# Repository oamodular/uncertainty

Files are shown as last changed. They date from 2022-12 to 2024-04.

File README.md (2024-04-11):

# *Uncertainty is now OSHW! both the software and the hardware!*

This readme needs to be updated to reflect this and to talk about the many other languages that people have used to create new firmware for Uncertainty. Right now I just want to say that the 4hp DIY version of Uncertainty is still a work in progress. It's been built, but we're in the process of trying to figure out why it doesn't work. The 2hp SMT version of Uncertainty is the one that we sell [here](https://oamodular.org/products/uncertainty).

What remains below is the previous readme. It contains the pinout for Uncertainty's Seeeduino Xiao RP2040 and some example Python code…

# Hack Uncertainty for fun and profit

Uncertainty's firmware is open-source and easy to swap with a humble USB-C cable. You can write your own firmware in C++, MicroPython, CircuitPython, and probably a bunch of other languages. It's startlingly easy to work and this document will outline the whole deal. Let's go…

## Uncertainty’s Heart

We’re working with the mighty RP2040, a dual-core 133 MHz arm processor that is just a silly amount of power for outputting gates. Heck, you can easily overclock to over 300 MHz. Really hoping people make some messed up things.

## Uncertainty’s I/O

- one CV input that can recognize signals -5v to +5v (resolution is functionally close to 10-bit, so there probably isn’t quite the precision for v/oct)
- eight +5v gate outputs that each have their own LED (if you turn on the gate, you turn on the LED; they can’t be decoupled)
- a three pin I2C connector (this feature is experimental and largely untested)

To access this I/O use the following pins. You can use other pins, but they won’t work. I don’t know why you’d use other pins. Use these pins:

| | Pin # |
| --- | --- |
|CV input|26|
|Gate 1|27|
|Gate 2|28|
|Gate 3|29|
|Gate 4|0|
|Gate 5|3|
|Gate 6|4|
|Gate 7|2|
|Gate 8|1|
|I2C SDA|6|
|I2C SCL|7|

## How to reinstall the default firmware

You hold down the boot button when you plug in the USB-C as described in the *Getting started* section. Then you drag ```uncertainty.uf2``` onto the RPI-RP2 disk. It should then unmount. All set! The same works for any .uf2 firmware.

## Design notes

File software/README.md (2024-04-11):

Right now, the default (and shipping) fw are the two in the c++ directory. The plan is to move to circuitpython because we think it’ll be the easiest for people to work with.

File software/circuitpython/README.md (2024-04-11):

# Running the scripts in this directory

Once you flash your Uncertainty with the most recent version of CircuitPython for RP2040, you should see `CIRCUITPY` show up as a disk on your computer. Copy the `examples` and `lib` from this directory into the `CIRCUITPY` drive. Then take make a copy of whatever script your want to run. Name the copy `code.py` and move it to the root level of `CIRCUITPY`. Now you’re running it!

# Making a .uf2 File

You’ll have to make a .uf2 file if you want others to be able to easily install what you have on your `CIRCUITPY`. To do this, install `picotool`. If you have have `brew`, just do a `brew install picotool`. Now run the command `picotool save --all ExampleNameHere.uf2`. Now you can pass this to your friend like a hacker.

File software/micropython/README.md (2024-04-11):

## Lets’s write a simple utility in MicroPython!

We’re going to turn Uncertainty into a device where you send it a voltage to select which of the 8 gates is active. Only one will be active at a time. 0v will activate the first gate. As you move towards -5v or +5v it switches to higher and highter gates, until it gets to gate 8.

### Getting set up

If we were using C we’d write our code in Arduino, but for MicroPython the easiest thing seems to be Thonny. So grab that and launch it. Now connect your Uncertainty to your computer over USB-C while holding down the boot button with the little B on it.

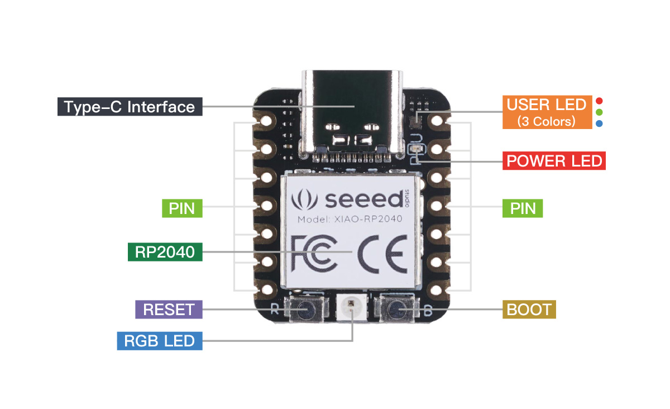
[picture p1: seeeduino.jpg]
Seeeduino Xiao RP2040 with a tiny boot button in the lower-right corner of the board


You should see RPI-RP2 on your desktop and Thonny should prompt you to install MicroPython onto the device. Do it. Just do it. Now Thonny can talk to Uncertainty whenever you plug in USB-C without holding down the boot button.

### Coding the code
These two lines import everything we need to deal get CV in and Gates out:

```python
import time
from machine import Pin, ADC
```

But our code doesn’t know which pin on the RP2040 is the CV in and which are the gates out. So let’s just set up a few variables:

```python
cv_in = ADC(Pin(26))
outs = [Pin(27, Pin.OUT),
        Pin(28, Pin.OUT),
        Pin(29, Pin.OUT),
        Pin(0, Pin.OUT),
        Pin(3, Pin.OUT),
        Pin(4, Pin.OUT),
        Pin(2, Pin.OUT),
        Pin(1, Pin.OUT)]
```

Now let’s make “the loop”. This is all we need to get a chunk of code to run a thousand times a second:

```python
while True:

    # your code here

    time.sleep(0.001)
```

For the actual logic we only need to do three things. (1) Figure out which gate should be active, (2) make it active, and (3) turn off the others.

1. CV comes in as a 16-bit number so we need to scale and offset it to convert the number of the active step:

    ```active_gate = abs(int((cv_in.read_u16() - 32768) / 4096))```

2. To make a gate active we give it a value of 1:

    ```outs[active_gate].value(1)```

3. Now we look through each gate and if it’s not the active one, we turn it off by passing in a value of 0:

```python
    for num in range (8):
        if num != active_gate:
            outs[num].value(0)
```

Now let’s bring this all together and look at the final code:

```python
import time
from machine import Pin, ADC

cv_in = ADC(Pin(26))
outs = [Pin(27, Pin.OUT),
        Pin(28, Pin.OUT),
        Pin(29, Pin.OUT),
        Pin(0, Pin.OUT),
        Pin(3, Pin.OUT),
        Pin(4, Pin.OUT),
        Pin(2, Pin.OUT),
        Pin(1, Pin.OUT)]

while True:

    active_gate = abs(int((cv_in.read_u16() - 32768) / 4096))

    for num in range (8):
        if num != active_gate:
            outs[num].value(0)

    outs[active_gate].value(1)

    time.sleep(0.0001)
```

That’s it. That’s a module, baby. A baby module. Done.

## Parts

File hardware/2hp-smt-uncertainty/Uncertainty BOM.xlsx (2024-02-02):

Item # | Designator | Quantity | Manufacturer | Mfg Part # | Description / Value | Package/Footprint | Type | Notes
1 | R18, R17, R13, R16, R12, R14, R19, R15 | 8 | TE Connectivity / Holsworthy | CRG0603F300R | Thick Film Resistors - SMD CRG0603 1% 300R | 1608 | SMD
2 | R5, R7, R6, R11, R9, R10, R8, R4 | 8 | Panasonic | ERJ-PA3D1001V | Thick Film Resistors - SMD 0603 1Kohm 0.5% Anti-Surge AEC-Q200 | 1608 | SMD
3 | D3, D2, D1 | 3 | Diodes Incorporated | 1N5819HW-7-F | Diode Schottky 40 V 1A Surface Mount SOD-123 | SOD-123 | SMD
4 | PS1 | 1 | Samtec | TSM-105-01-L-DH | TSM - Samtec 2.54mm Dual Row Horizontal Surface Mount Header 5.84mm Post Height (01) | SMD | SMD
5 | H1, H2 | 2 | Wurth Elektronik | 7466303 | Terminals WP-SMRA SMD Block 7mm | SMD | SMD | Component should be mounted so screw hole faces left edge of board
6 | J8, J4, J2, J9, J3, J5, J7, J1, J6 | 9 | Switchcraft | 35RASMT2AHNTRX | Phone Connectors 3.5mm SMT MONO T/R 3A CLOSED | SMD | SMD
7 | D8, D10, D5, D9, D11, D6, D7, D4 | 8 | Kingbright | APPA3010SURCK | Standard LEDs - SMD 3x1mm SMD RA RED | SMD | SMD
8 | U1 | 1 | Texas Instruments | LM1117IMPX-3.3_NOPB | 800-mA 15-V linear voltage regulator | SOT-223-4 | SMD
9 | R1, R3, R2 | 3 | Panasonic | ERJ-2RKF1003X | Thick Film Resistors - SMD 0402 100Kohms 1% AEC-Q200 | 1005 | SMD
10 | C1 | 1 | Panasonic | EEE-FT1E220AR | Aluminum Electrolytic Capacitors - SMD 22uF 25volts 4x5.8mm SMD | SMD | SMD
11 | U5 | 1 | Seeed | 102010428 | RP2040 XIAO RP2040 series ARM Cortex-M0+ MCU 32-Bit Embedded Evaluation Board | SMD | SMD | Please use surface mount soldering, NOT through-hole
12 | U2 | 1 | STMicroelectronics | L7805CDT-TR | Linear Voltage Regulator IC Positive Fixed 1 Output 1.5A DPAK | TO-252 | SMD
13 | U4, U3 | 2 | Texas Instruments | SN74HCS125QDRQ1 | Automotive Schmitt-trigger inputs quadruple bus buffer gates with 3-state outputs 14-SOIC -40 to 125 | SOIC-14 | SMD
14 | J10 | 1 | Samtec | TSM-103-01-L-SH | TSM - Samtec 2.54mm Single Row Horizontal Surface Mount Header 5.84mm Post Height | SMD | SMD

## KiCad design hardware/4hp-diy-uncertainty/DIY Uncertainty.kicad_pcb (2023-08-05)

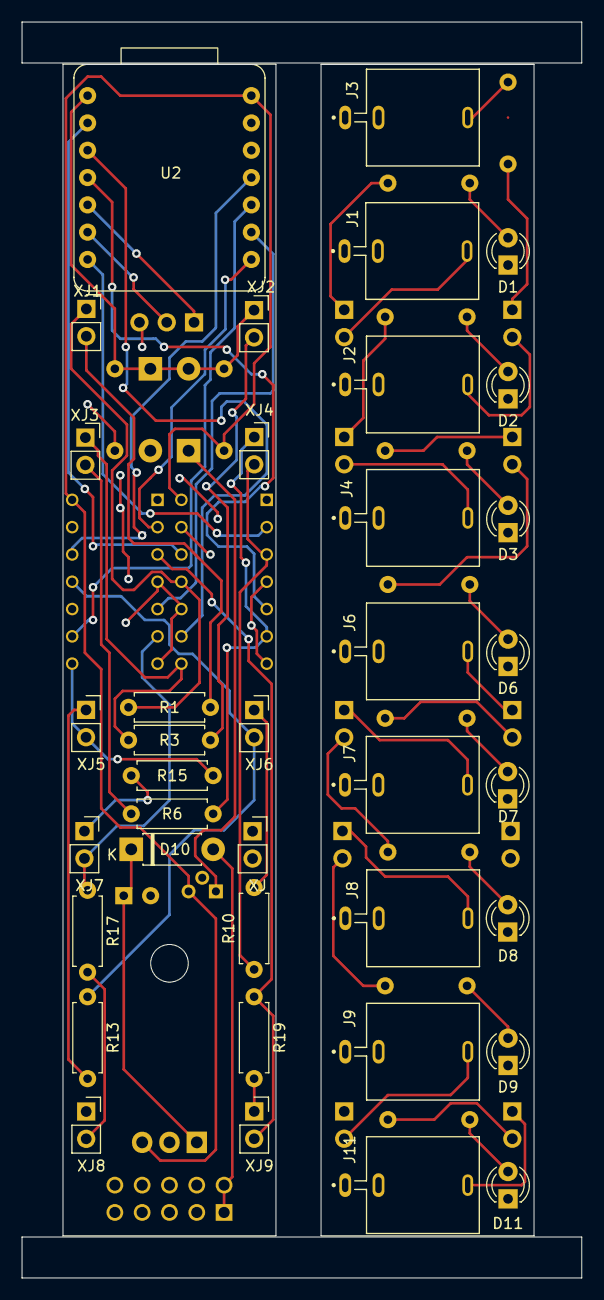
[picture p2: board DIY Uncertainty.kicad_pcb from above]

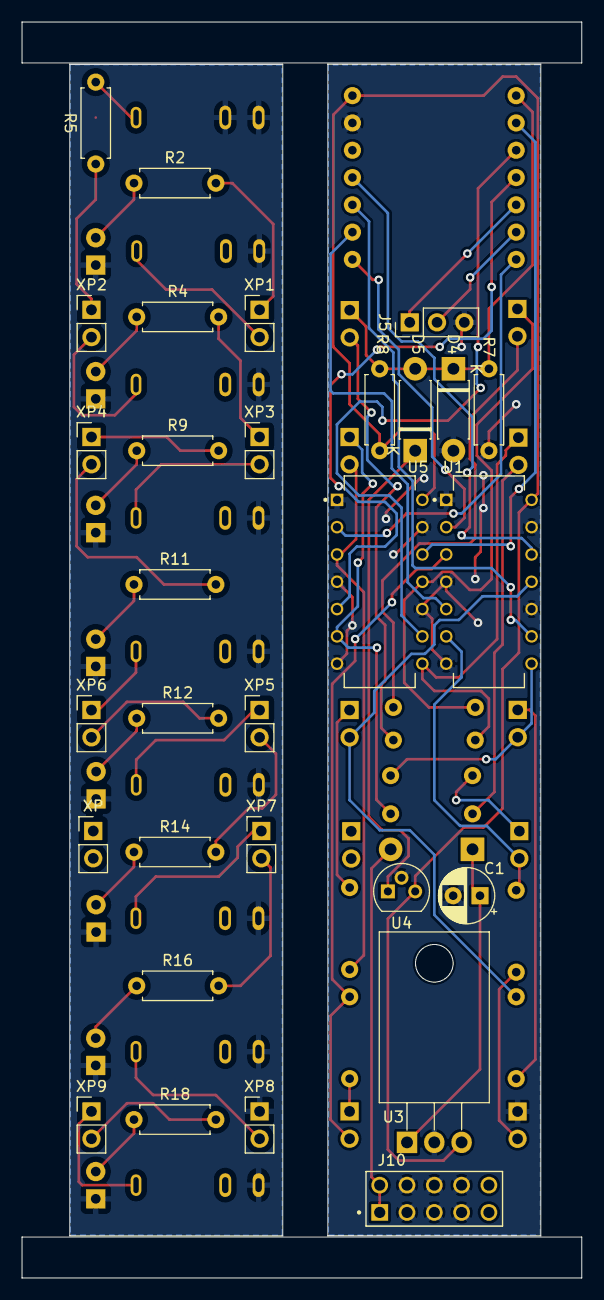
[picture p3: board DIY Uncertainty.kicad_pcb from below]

Board: 2 copper layers, 52.1 x 116.8 mm, 67 parts (30 on the bottom side), 41 nets.

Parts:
C1: 22uF; CP_Radial_D5.0mm_P2.50mm
D1, D2, D3, D6, D7, D8, D9, D11: LED; LED-THT Red Angle130-L-47XEC
D4, D5, D10: 1N5819; D_DO-41_SOD81_P7.62mm_Horizontal
J1, J2, J3, J4, J6, J7, J8, J9, J11: AudioJack2; Socket-3.5mm THT-Thonkiconn PJ398SM-12
J5: Conn_01x03_Pin; PinHeader_1x03_P2.54mm_Vertical
J10: Connector-2x5 2.54p THT-861400102YO9323LF
R1, R3, R6, R10, R13, R15, R17, R19: 1K; R_Axial_DIN0207_L6.3mm_D2.5mm_P7.62mm_Horizontal
R2, R4, R9, R11, R12, R14, R16, R18: 300; R_Axial_DIN0207_L6.3mm_D2.5mm_P7.62mm_Horizontal
R5, R7, R8: 100K; R_Axial_DIN0207_L6.3mm_D2.5mm_P7.62mm_Horizontal
U1, U5: SN74HCT125DE4; Quad Bus-Tri-State Quad Bus non-inverting THT-SN74HCT125NE4
U2: SeeeduinoXIAO; Microcontroller-XIAO RP2040
U3: L7805CV; TO-220-3_Horizontal_TabDown
U4: L78L33ACZTR; TO-92
XJ, XJ1, XJ2, XJ3, XJ4, XJ5, XJ6, XJ7, XJ8, XJ9: PinSocket_1x02_P2.54mm_Vertical
XP, XP1, XP2, XP3, XP4, XP5, XP6, XP7, XP8, XP9: PinHeader_1x02_P2.54mm_Vertical

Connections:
+3.3V: D5.1 (K), U4.1 (VO)
+5V: R8.2, U1.14 (VCC), U2.14 (5V), U3.3 (VO), U4.3 (VI), U5.14 (VCC)
+12V: D10.2 (A), J10.01 (Pin_1), J10.02 (Pin_2)
GND: C1.2, D1.1 (K), D2.1 (K), D3.1 (K), D4.2 (A), D6.1 (K), D7.1 (K), D8.1 (K), D9.1 (K), D11.1 (K), J1.1, J2.1, J3.1, J3.2, J4.1, J5.3, J6.1, J7.1, J8.1, J9.1, J10.03 (Pin_3), J10.04 (Pin_4), J10.05 (Pin_5), J10.06 (Pin_6), J10.07 (Pin_7), J10.08 (Pin_8), J11.1, R7.1, U1.1 (1~OE), U1.4 (2~OE), U1.7 (GND), U1.10 (3~OE), U1.13 (4~OE), U2.13 (GND), U3.2 (GND), U4.2 (GND), U5.1 (1~OE), U5.4 (2~OE), U5.7 (GND), U5.10 (3~OE), U5.13 (4~OE), XJ8.1, XP8.1
unnamed: D1.2 (A), R2.1
unnamed: D2.2 (A), R4.1
unnamed: D3.2 (A), R9.1
unnamed: D4.1 (K), D5.2 (A), R5.1, R7.2, R8.1, U2.1 (PA02_A0_D0), XJ2.1, XP2.1
unnamed: D6.2 (A), R11.1
unnamed: D7.2 (A), R12.1
unnamed: D8.2 (A), R14.1
unnamed: D9.2 (A), R16.1
unnamed: C1.1, D10.1 (K), U3.1 (VI)
unnamed: D11.2 (A), R18.1
unnamed: J1.3, R1.2, XJ1.2, XP1.2
unnamed: J2.3, R3.2, XJ2.2, XP2.2
unnamed: J3.3, R5.2
unnamed: J4.3, R6.2, XJ3.2, XP3.2
unnamed: J5.1, U2.5 (PA8_A4_D4_SDA)
unnamed: J5.2, U2.6 (PA9_A5_D5_SCL)
unnamed: J6.3, R10.2, XJ6.1, XP6.1
unnamed: J7.3, R13.2, XJ5.1, XP5.1
unnamed: J8.3, R15.2, XJ7.1, XP7.1
unnamed: J9.3, R17.2, XJ8.2, XP8.2
unnamed: J11.3, R19.2, XJ9.1, XP9.1
unnamed: U1.2 (1A), U2.8 (PB09_A7_D7_RX)
unnamed: R18.2, R19.1, U1.3 (1Y), XJ9.2, XP9.2
unnamed: U1.5 (2A), U2.9 (PA7_A8_D8_SCK)
unnamed: R16.2, R17.1, U1.6 (2Y), XJ7.2, XP7.2
unnamed: U1.9 (3A), U2.10 (PA5_A9_D9_MISO)
unnamed: R14.2, R15.1, U1.8 (3Y), XJ5.2, XP5.2
unnamed: U1.12 (4A), U2.11 (PA6_A10_D10_MOSI)
unnamed: R12.2, R13.1, U1.11 (4Y), XJ6.2, XP6.2
unnamed: U2.2 (PA4_A1_D1), U5.12 (4A)
unnamed: U2.3 (PA10_A2_D2), U5.9 (3A)
unnamed: U2.4 (PA11_A3_D3), U5.5 (2A)
unnamed: U2.7 (PB08_A6_D6_TX), U5.2 (1A)
unnamed: R10.1, R11.2, U5.3 (1Y), XJ4.2, XP4.2
unnamed: R6.1, R9.2, U5.6 (2Y), XJ4.1, XP4.1
unnamed: R3.1, R4.2, U5.8 (3Y), XJ3.1, XP3.1
unnamed: R1.1, R2.2, U5.11 (4Y), XJ1.1, XP1.1

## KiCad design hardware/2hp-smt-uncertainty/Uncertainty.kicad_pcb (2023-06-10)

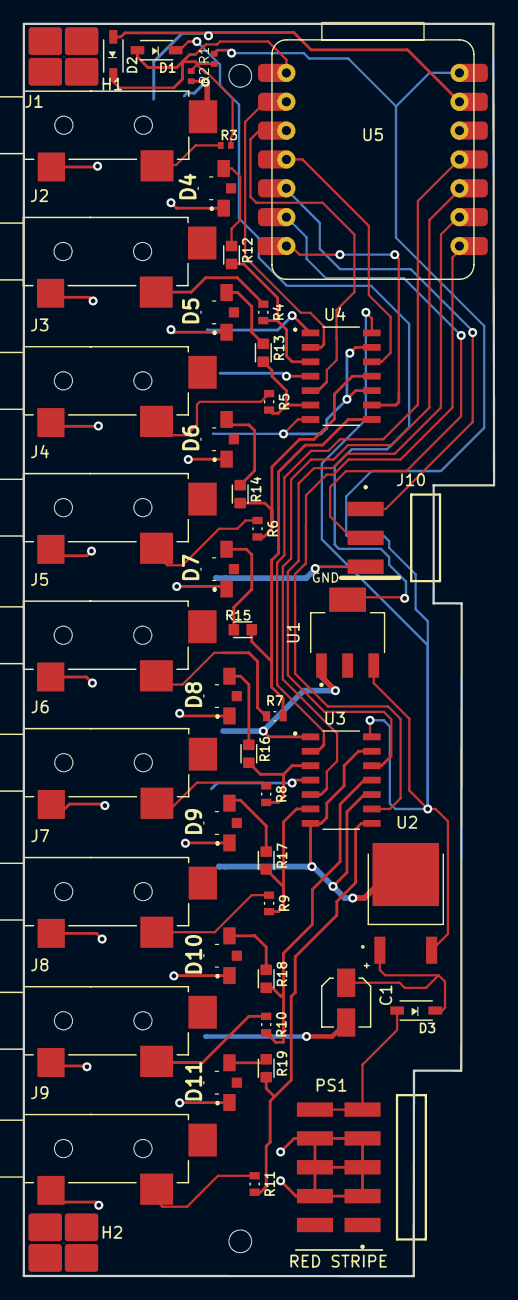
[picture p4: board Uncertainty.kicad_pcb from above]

Board: 2 copper layers, 41.4 x 110.3 mm, 49 parts (0 on the bottom side), 4 nets.

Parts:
C1: CAP_EEE-FT1E220AR
D1, D2, D3: SOD3715X145N; Diode-1N5819HW-7-F
D4, D5, D6, D7, D8, D9, D10, D11: APPA3010SURCK; LED-SMD Red SideEmit Angle30 3x1mm -APPA3010SURCK
H1, H2: Wurth 7466303; Hardware-Right angle SMT mounting block-Wurth 7466303
J1, J2, J3, J4, J5, J6, J7, J8, J9: SWITCHCRAFT_35RASMT2AHNTRX
J10: SAMTEC_TSM-103-01-L-SH
PS1: SAMTEC_TSM-105-01-L-DH
R1, R2, R3: In Resist-ERJ-2RKF1003X
R4, R5, R6, R7, R8, R9, R10, R11: Out Resist-RES_ERJPA3D1001V
R12, R13, R14, R15, R16, R17, R18, R19: RESC1608X50N
U1: VREG_LM1117IMPX-3.3/NOPB; VREG_LM1117IMPX-3.3_NOPB
U2: VREG_L7805CDT-TR
U3, U4: SN74HCS125QDRQ1; Quad Bus-SMD SN74HCS125QDRQ1
U5: XIAO-RP2040

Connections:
3.3V: D1.C, U1.4
5V: R1.2, U1.3, U2.2, U3.14, U4.14, U5.14
Ground: C1.2, D2.A, D4.1, D5.1, D6.1, D7.1, D8.1, D9.1, D10.1, D11.1, J1.3, J1.5, J2.5, J3.5, J4.5, J5.5, J6.5, J7.5, J8.5, J9.5, J10.03, PS1.03, PS1.04, PS1.05, PS1.06, PS1.07, PS1.08, R2.2, U1.1, U2.3, U3.1, U3.4, U3.7, U3.10, U3.13, U4.1, U4.4, U4.7, U4.10, U4.13, U5.13
Power: C1.1, D3.A, D3.C, PS1.09, PS1.10, U1.2, U2.1

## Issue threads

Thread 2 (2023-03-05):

jumpers across i2c pins should flip meter

oliviaartz, 2023-03-05:

oliviaartz, 2023-03-07:
reassigned to me for testing

Closed 2023-03-14.

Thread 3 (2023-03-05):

send cv input to midi host as ctl data

oliviaartz, 2023-03-05:

oliviaartz, 2023-03-07:
i need to do more testing but it wasn’t showing up for me. will test more

oliviaartz, 2023-03-08:
it won’t show up in max or ableton. i’ve tested another midi controller and it shows up just fine

working on this firmware only came up because i thought it would be a fun way to work on burst. i’m just continuing to work entirely in max. so let’s backburner this until we’re ready to give it love and attention

Closed 2024-04-28.

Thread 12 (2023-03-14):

Liv’s desired behavior for a burst mode algorithm [outlet:1] [polarity:positive]

oliviaartz, 2023-03-14:
The berst continues for as long as the gate is open. The gate is continuously polled for its voltage  because the voltage level can change the speed of the burst while it is happening. At 5v it is one burst per second. When voltage is lower the bursts come out faster. If they’re lowered to around 2v, a fast percussive sound (snare) will be triggered so fast it will sound like just one extended event. But between 2v and 5v, the hits should be distinct sounds.

The numbers listed are just meant to be a guide.

If this experiment goes well, we build on it.

Closed 2023-04-30.

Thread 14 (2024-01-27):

kicad file for 2HP module appears broken

KeLaiFu, 2024-01-27:
I was looking at the kicad file and it seems that the net (I think that's the term...) is broken on a lot of the components. The jacks for example just have numbered pads instead of references to their connection as usual. This means the layout can't be edited very easily, which I was going to attempt.

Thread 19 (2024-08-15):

4hp-diy-uncertainty hardware KiCad has no GND traces

dlakwi, 2024-08-15:
The KiCad design for the 4hp DIY hardware has no GND traces.
The net includes all the GND pads but no traces have been routed.
Is there supposed to be any area fills, or is there not enough room?

Closed 2024-08-15.

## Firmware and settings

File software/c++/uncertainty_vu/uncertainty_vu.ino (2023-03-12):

#include <Arduino.h>
#include <math.h>
#include <vector>
#include "hardware/gpio.h"
#include "pico/stdlib.h"
#include "hardware/adc.h"

#include "fp.hpp"

using namespace fp;

#define TIMER_INTERVAL ((int)(1000000.0/40000.0))
#define SAMPLE_RATE (1000000.0/TIMER_INTERVAL)

// number of gate outs
#define NUM_GATES 8

// audio/cv "real" numbers
typedef fp_t<int,12> cv_t;

// hold pins for gates
int gatePins[] = {27,28,29,0,3,4,2,1};
// ADC input pin
int inputPin = 26;
// last ADC value read, used to detect rising edge
cv_t lastInput = cv_t(0.0);

// trigger generator
class Trigger {
public:
  int phase;
  int output;
  int width;
  Trigger(int output=0, int widthInSamples=100) {
    this->output = output;
    this->width = widthInSamples;
    this->phase = widthInSamples+1;
  }
  void Reset() {
    phase = 0;
  }
  bool Done() {
    return phase > width;
  }
  void Process() {
    gpio_put(gatePins[output], phase < width ? 1 : 0);
    if(phase <= width) phase++;
  }
};

class DCFilter {
private:
  // we're doing filtering of a sort, so let's
  // use high precision values
  typedef fp_t<int, 26> avg_t;
  avg_t lastVal;
public:
  DCFilter() {
    lastVal = 0;
  }
  cv_t Process(cv_t in) {
    avg_t delta = in - lastVal;
    lastVal += delta>>13; // to modify, shift by more bits for slower response to DC/low-freq input or fewer for more aggressive filtering
    return in - cv_t(lastVal);
  }
};

class MeterBallistics {
private:
  // we're doing filtering of a sort, so let's
  // use high precision values
  typedef fp_t<int, 24> slew_t;
public:
  slew_t lastVal;
  MeterBallistics() {
    lastVal = 0;
  }
  cv_t Process(cv_t in) {
    // get magnitude of input
    in = in > slew_t(0) ? in : -in;
    // how much did the magnitude of the input value change since last time?
    slew_t delta = slew_t(in) - lastVal;
    // if we're decreasing, seriously limit how quickly we can decrease
    if(delta < slew_t(0)) {
      // really hacky but efficient divide by 4096 samples, which is like 100ms fall time
      lastVal += delta>>12; // modify to alter fall time, bigger number longer fall
    } else { // otherwise just adjust by the difference, mimicking the input
      lastVal += delta;
    }
    return cv_t(lastVal);
  }
};

// cute little led animation
void startupSequence() {
  uint32_t startupCounter = 0;
  // startup sequence
  while(startupCounter<128*8) {
    int pinIndex = startupCounter>>7;
    for(int i=0;i<8;i++) {
      if(i==pinIndex) {
        gpio_put(gatePins[pinIndex], startupCounter%128 < 120);
      } else {
        gpio_put(gatePins[i], 0);
      }
    }
    startupCounter++;
    delay(1);
  }
}

// classes for handling gate/trigger output
Trigger* triggers[NUM_GATES];
MeterBallistics meter;
DCFilter dcFilter;

cv_t debugVal = 0;

bool vuIsInverted = false;
bool illuminateMax = false;

// audio rate callback- meat of the program goes here
static bool audioHandler(struct repeating_timer *t) {
  // poll ADC and convert from 12 bit value to [-1.0, 1.0]
  cv_t input = (cv_t(adc_read() - (1<<11)) >> 11) * cv_t(5.0 / 4.42) - cv_t(0.04);

  debugVal = input;

  // DC filter input
  input = dcFilter.Process(input);

  // meter processing
  input = meter.Process(input);

  // scale output levels to go from 0 to 8
  int level = std::min(8, int(input*fp_t<int,0>(8)));

  // set outputs
  for(int i=0;i<8;i++) {
    if(i+1 <= level) {
      int triggerIndex = vuIsInverted ? i : 7-i;
      if(!illuminateMax || (i+1) == level) triggers[triggerIndex]->Reset();
    }
    triggers[i]->Process();
  }

  // record the current input for the next calc
  lastInput = input;

  return true;
}

struct repeating_timer _timer_;

#define CONFIG_PIN_TOP 6
#define CONFIG_PIN_BOTTOM 7

bool jumperBottomGround() {
  gpio_disable_pulls(CONFIG_PIN_BOTTOM);
  gpio_set_dir(CONFIG_PIN_BOTTOM, GPIO_IN);
  gpio_pull_up(CONFIG_PIN_BOTTOM);
  delay(1);
  return !gpio_get(CONFIG_PIN_BOTTOM);
}

bool jumperTopBottom() {
  gpio_disable_pulls(CONFIG_PIN_TOP);
  gpio_disable_pulls(CONFIG_PIN_BOTTOM);
  gpio_set_dir(CONFIG_PIN_TOP, GPIO_IN);
  gpio_set_dir(CONFIG_PIN_BOTTOM, GPIO_OUT);
  gpio_pull_up(CONFIG_PIN_TOP);
  gpio_put(CONFIG_PIN_BOTTOM, 0);
  delay(1);
  return !gpio_get(CONFIG_PIN_TOP);
}

void setup() {
  // 2x overclock for MAX POWER
  set_sys_clock_khz(250000, true);

  // initialize ADC
  adc_init();
  adc_gpio_init(inputPin);
  adc_select_input(0);
  
  // initialize gate out pins
  for(int i=0; i<NUM_GATES; i++) {
    int pin = gatePins[i];
    gpio_init(pin);
    gpio_set_dir(pin, GPIO_OUT);
    triggers[i] = new Trigger(i, 500 /* modify/increase to hold gates open for longer */ );
  }

  // init config pins
  gpio_init(CONFIG_PIN_TOP); 
  gpio_init(CONFIG_PIN_BOTTOM);

  // oooh pretty
  startupSequence();

  // audio callback
  add_repeating_timer_us(-TIMER_INTERVAL, audioHandler, NULL, &_timer_);

  // init serial debugging
  Serial.begin(9600);
}

void loop() {
  Serial.println(float(debugVal));
  vuIsInverted = jumperBottomGround();
  delay(1);
  illuminateMax = jumperTopBottom();
  delay(1);
}

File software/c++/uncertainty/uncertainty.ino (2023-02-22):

#include <Arduino.h>
#include <math.h>
#include <vector>
#include "hardware/gpio.h"
#include "pico/stdlib.h"
#include "hardware/adc.h"

#include "fp.hpp"

using namespace fp;

// should gates be toggled on clock, or set to the dice roll on clock?
#define TOGGLE_GATES false

// number of gates
#define NUM_GATES 8

typedef fp_t<int, 12> cv_t;

// hold pins for gates
int gatePins[] = {27,28,29,0,3,4,2,1};
// gate states
int gateStates[] = {0,0,0,0,0,0,0,0};
// gate probabilities
cv_t gateProbabilities[] = {cv_t(99/100.0),cv_t(91/100.0),cv_t(67/100.0),cv_t(50/100.0),cv_t(33/100.0),cv_t(13/100.0),cv_t(5/100.0),cv_t(1/100.0)};
// inv gate probabilities
cv_t invGateProbabilitiesMax[] = {cv_t(99.5/100.0),cv_t(80/100.0),cv_t(50/100.0),cv_t(20/100.0)};
cv_t invGateProbabilitiesMin[] = {cv_t(20/100.0),cv_t(50/100.0),cv_t(80/100.0),cv_t(99.5/100.0)};
// ADC input pin
int inputPin = 26;
// ADC threshold from low to high (tunable)
cv_t lowToHighInputThreshold = cv_t(1.0);
// ADC threshold from high to low (tunable)
cv_t highToLowInputThreshold = cv_t(0.5);
// last ADC value read, used to detect rising edge
cv_t lastInput = cv_t(0.0);
// bool to track input state for debounce/hysteresis
bool isInputHigh = false;
// bool to track if output has been triggered negatively
bool negTriggered = false;
// int to track how many samples we've accumulated
int samplesAccumulated = 0;
// frac to track max value
cv_t maxValue = 0;
// trigger polarity
int triggerPolarity = 0;
// special threshold for positive triggers only
cv_t positiveTriggerThreshold = cv_t(3.0);

uint32_t startupCounter = 0;

void setup() {
  // 2x overclock for MAX POWER
  //set_sys_clock_khz(250000, true);

  Serial.begin(9600);
  
  // initialize ADC
  adc_init();
  adc_gpio_init(inputPin);
  adc_select_input(0);
  gpio_set_pulls(inputPin, false, false);
  
  // initialize gate out pins
  for(int i=0; i<NUM_GATES; i++) {
    int pin = gatePins[i];
    gpio_init(pin);
    gpio_set_dir(pin, GPIO_OUT);
  }
}

void loop() {
  // poll ADC as fast as possible
  cv_t input = (cv_t(adc_read())>>12)*cv_t(10.0) - cv_t(5.0);
  bool polarity = input > cv_t(0.0) ? true : false;
  input = polarity ? input : -input;

  // startup sequence
  if(startupCounter<128*8) {
    int pinIndex = startupCounter>>7;
    for(int i=0;i<8;i++) {
      if(i==pinIndex) {
        gpio_put(gatePins[pinIndex], startupCounter%128 < 120);
      } else {
        gpio_put(gatePins[i], 0);
      }
      gateStates[i] = 0;
    }
    startupCounter++;
    delay(1);
    lastInput = input;
    return;
  }

  // if there's a rising edge...
  if(polarity && isInputHigh == false) {
    if(input > positiveTriggerThreshold) {
      Serial.println((float)input);
      isInputHigh = true;
      triggerPolarity = 1;
      // iterate over the gates
      for(int i=0; i<NUM_GATES; i++) {
        // wrap random number generation
        // to a max of roughly 1000 
        cv_t diceRoll = cv_t(rand() & 0x3FFF)>>14;
  
        // modify this #define at the top of the
        // file to change how the module works
        if(TOGGLE_GATES) {
          // toggle gate states according to probability
          if(diceRoll < gateProbabilities[i]) {
            // if gate state is 0, set it to 1
            // if gate state is 1, set it to 0
            gateStates[i] = gateStates[i] == 0 ? 1 : 0;
          }
        } else {
          // set gate states to result of dice roll
          gateStates[i] = diceRoll < gateProbabilities[i] ? 1 : 0;
        }
        
        // set the gpio pin
        gpio_put(gatePins[i], gateStates[i]);
      }
    }
  }

  // if there's a negative rising edge
  if(!polarity && isInputHigh == false) {
    if(input > lowToHighInputThreshold) {
      isInputHigh = true;
      negTriggered = true;
      triggerPolarity = -1;
    }
  }

  if(negTriggered) {
    if(samplesAccumulated < 4) {
      if(!polarity) {
        maxValue = max(maxValue, min(cv_t(1.0), cv_t((max(input, cv_t(1.0))-cv_t(1.0))*cv_t(0.3))));
      }
      samplesAccumulated++;
    } else {
      // iterate over the gates
      for(int i=0; i<NUM_GATES/2; i++) {
        // wrap random number generation
        // to a max of roughly 1000 
        cv_t diceRoll = cv_t(rand() & 0x3FFF)>>14;

        // modify this #define at the top of the
        // file to change how the module works
        if(TOGGLE_GATES) {
          // toggle gate states according to probability
          if(diceRoll < (cv_t(invGateProbabilitiesMax[i]*maxValue) + cv_t(invGateProbabilitiesMin[i]*(cv_t(1)-maxValue)))) {
            // if gate state is 0, set it to 1
            // if gate state is 1, set it to 0
            gateStates[i] = gateStates[i] == 0 ? 1 : 0;
          }
        } else {
          // set gate states to result of dice roll
          gateStates[i] = diceRoll < (cv_t(invGateProbabilitiesMax[i]*maxValue) + cv_t(invGateProbabilitiesMin[i]*(cv_t(1)-maxValue))) ? 1 : 0;
        }
        
        // set the gpio pins
        gpio_put(gatePins[i*2], gateStates[i]);
        gpio_put(gatePins[i*2+1], gateStates[i] ? 0 : 1);
      }

      maxValue = 0;
      samplesAccumulated = 0;
      negTriggered = false;
    }
  }

  // turn off gates when input goes low
  if(triggerPolarity < 0) {
    if(input < highToLowInputThreshold && isInputHigh == true) {
      isInputHigh = false;
      for(int i=0; i<NUM_GATES; i++) {
        gpio_put(gatePins[i], 0);
      }
    }
  } else {
    if(input < (positiveTriggerThreshold - cv_t(0.5)) && isInputHigh == true) {
      Serial.println((float)input);
      isInputHigh = false;
      for(int i=0; i<NUM_GATES; i++) {
        gpio_put(gatePins[i], 0);
      }
    }
  }
  
  // record the current input for the next calc
  lastInput = input;
}

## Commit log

2022-12-26 Fixed some bugs. Made it so 0v is gate 1 and moving to higher (or lower!) voltage moves to a higher gate.
    [boot.py]
2023-02-12 moving the current stable uncertainty
2023-02-14 Making the digital schmidt trigger threshold voltages assymetrical to deal with floating inputs without leaving all LEDs on.
2023-02-22 Fixing some weird edge cases where Uncertainty might get temporarily stuck in a weird state.
    [uncertainty.ino]
2023-03-03 Adding DC offset filter to input.
2023-03-07 Adding options for jumping i2c pins together to enable "max amplitude only" mode or to flip the meter display.
    [uncertainty_vu.ino]
2023-06-10 adding uncertainty hardware and license
    [DIY Plate.kicad_pcb, DIY Plate.kicad_sch, DIY Uncertainty.kicad_pcb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]
2023-08-05 misc updates from kate
    [DIY Uncertainty.kicad_pcb, DIY Uncertainty.kicad_sch]
2023-08-05 ignore kicad cache folders
2024-02-02 a bom
    so people can actually build this thing
    [Uncertainty BOM.xlsx]
2024-04-11 Adding CircuitPython code and some documenation
2024-04-28 tweak to coin flip logic
    [uncertainty.py]
